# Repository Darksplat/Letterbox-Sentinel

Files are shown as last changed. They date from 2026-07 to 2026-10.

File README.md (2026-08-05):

# Letterbox Sentinel

Letterbox Sentinel is a battery-powered ESP8266/Wemos D1 Mini mail detector for Home Assistant using MQTT Discovery.

Current firmware: **v3.1.0**

## What it does

- Detects each separate delivery through the mail slot using an IR break-beam sensor.
- Supports multiple deliveries per day, even while `Mail Waiting` is already ON.
- Keeps a persistent `Mail Waiting` state until the mailbox is emptied.
- Keeps a persistent lifetime delivery counter.
- Records the most recent mail detection time.
- Supports NFC-driven collection through Home Assistant, including the collector name.
- Publishes BME280 temperature, humidity and sea-level-corrected pressure.
- Monitors a 2S 18650 battery pack through A0.
- Publishes Wi-Fi, network and device diagnostics to Home Assistant.
- Supports Arduino OTA updates.
- Uses timed deep sleep outside delivery hours to extend battery life.
- Uses DHCP by default so it can work on different home-network address ranges.

## Daily operating schedule

### Monday-Saturday

- **07:30**: IR mail monitoring begins.
- **17:00**: IR monitoring ends and scheduled deep-sleep operation begins.
- Every genuine delivery:
  - sets `Mail Waiting` to ON;
  - increments the persistent delivery counter;
  - updates `Last Mail Detected`;
  - publishes a mail event to MQTT;
  - turns the IR emitter off for 30 seconds;
  - automatically rearms the IR detector after the lockout.

The detector continues to accept later deliveries during the same day. Mail does not need to be collected before another delivery can be detected.

### Sunday

The IR system remains disabled and the ESP8266 uses scheduled deep sleep.

Deep sleep is performed in chunks of up to 60 minutes. The final sleep before 07:30 is shortened so the device wakes close to the monitoring start time.

## Mail Waiting and delivery counting

`Mail Waiting` and the delivery detector are deliberately independent:

- `Mail Waiting` answers: **Is there uncollected mail in the box?**
- The delivery counter answers: **How many separate deliveries have been detected?**

Example:

```text
10:00 Australia Post delivery
Mail Waiting: ON
Letter Counter: 1

14:00 Courier delivery
Mail Waiting: still ON
Letter Counter: 2

16:00 NFC collection
Mail Waiting: OFF
Letter Counter: still 2
```

Clearing `Mail Waiting` does not reset the lifetime counter.

## Hardware

- Wemos/LOLIN D1 Mini (ESP8266)
- BME280 environmental sensor
- IR break-beam receiver
- IR emitter
- BC547 transistor for IR emitter switching
- 2S 18650 battery pack
- TRACO Power TSR 1-2433 3.3 V switching regulator
- 330 kΩ / 100 kΩ battery voltage divider
- Optional 100 nF capacitor on A0
- D0/GPIO16 to RST connection for timed deep-sleep wake

### Custom PCB

A custom 2-layer KiCad carrier PCB has been developed for Letterbox Sentinel. The hardware design is documented under [`hardware/`](hardware/README.md).

Key PCB features:

- Approximately **64 mm × 50 mm**.
- Socketed Wemos D1 Mini for serviceability.
- Socketed **TRACO TSR 1-2433** 3.3 V regulator.
- Choice of **5.5 × 2.1 mm centre-positive barrel jack** or **AMASS XT60PW-F female** battery input.
- Raw 2S battery monitoring before regulation using the 330 kΩ / 100 kΩ divider.
- 1000 µF / 25 V reservoir capacitor on the 3.3 V rail.
- BC547-switched IR transmitter output.
- Female sockets for IR TX, IR RX and BME280.
- Bottom-layer GND copper plane.
- Through-hole construction for practical hand assembly and repair.

The routed board passed KiCad DRC with **0 errors and 0 unconnected pads** during the manufacturing review.

## Pinout

| Function | D1 Mini pin |
|---|---|
| BME280 SCL | D1 |
| BME280 SDA | D2 |
| IR receiver signal | D5 |
| IR emitter transistor control | D6 |
| Battery voltage | A0 |
| Deep-sleep wake | D0/GPIO16 → RST |

## IR emitter switching

D6 is a control signal only. Do not power the IR emitter directly from D6.

```text
D6 ---- 4.7k ---- BC547 base
BC547 emitter ---- GND
BC547 collector -- IR emitter negative
IR emitter positive -- 3.3 V rail
```

The IR receiver remains connected to D5.

## Battery monitoring

Current external divider:

```text
Battery + ---- 330k ----+---- A0
                        |
                      100k
                        |
Battery - ------------- GND
```

The current firmware uses:

```cpp
const float ADC_FULL_SCALE_V = 3.20F;
const float BATTERY_DIVIDER_RATIO = 5.35F;
const float BATTERY_CALIBRATION = 0.975F;
```

These values were calibrated against a multimeter on the installed Wemos D1 Mini and divider network. Other boards may require recalibration.

## BME280 pressure

Pressure is corrected to sea level using the configured site altitude:

```cpp
const float SITE_ALTITUDE_METERS = 230.0F;
```

The default is approximately 230 m above sea level for Maiden Gully, Victoria. Change this value for another installation location.

## Network configuration

Firmware v3.1.0 uses **DHCP by default**:

```cpp
const bool USE_STATIC_IP = false;
```

This means the device can join networks using address ranges such as:

- `192.168.0.x`
- `192.168.1.x`
- `10.x.x.x`
- `172.16.x.x`

For a stable address, the recommended approach is to leave DHCP enabled and create a DHCP reservation in the router.

Static addressing is optional. The static IP, gateway, subnet and DNS values are ignored unless:

```cpp
const bool USE_STATIC_IP = true;
```

## MQTT broker address

The public firmware defaults to:

```cpp
const char* MQTT_HOST = "homeassistant.local";
```

This may be replaced with:

- the MQTT broker hostname;
- the Home Assistant hostname if the broker runs there; or
- the broker's IP address.

The MQTT broker does not have to run on Home Assistant.

## NFC mail collection

The NFC tag is read by a phone running Home Assistant. It is not read directly by the Wemos.

Home Assistant should publish to:

```text
letterbox_sentinel/command/mail_collected
```

Example payload:

```json
{"collector":"Leigh"}
```

The firmware then:

- clears `Mail Waiting`;
- stores and publishes the collector name;
- stores and publishes the collection time;
- keeps the lifetime delivery counter unchanged.

The manual **Clear Mail Waiting** button performs the same state clear without requiring NFC.

## Home Assistant MQTT Discovery

The firmware automatically creates sensors, binary sensors and buttons in Home Assistant using MQTT Discovery.

### Stable identifier rule

From firmware **v2.2.0 onward**, MQTT Discovery identifiers are treated as a stable API:

- Discovery object IDs remain unchanged across firmware revisions.
- `unique_id` values remain unchanged across firmware revisions.
- Display names, icons, units, calibration and firmware logic may change without changing identifiers.
- If an entity must be removed or replaced, the obsolete retained MQTT Discovery topic must be cleared.

This prevents duplicate and orphaned Home Assistant entities during upgrades.

## Home Assistant controls

Current controls include:

- Clear Mail Waiting
- Reset Letter Counter
- Test Mail Detection
- Restart
- Enter Safe Mode
- Exit Safe Mode

The **Test Mail Detection** button creates a test event but does not start the 30-second physical IR lockout.

## Home Assistant entities

Important entities include:

- Mail Waiting
- Mail Slot Beam
- IR Emitter Active
- Letter Counter
- Last Mail Detected
- Last Collected By
- Last Collection Time
- Battery
- Battery Voltage
- Low Battery
- Temperature
- Humidity
- Sea Level Pressure
- Wi-Fi Signal
- Uptime
- IP Address
- Wi-Fi SSID
- MAC Address
- Gateway
- DNS Server
- Reset Reason
- Firmware
- Safe Mode
- Network Time Valid

## Required Arduino libraries

Install using **Arduino IDE → Library Manager**:

- PubSubClient
- ArduinoJson 7
- Adafruit BME280 Library
- Adafruit Unified Sensor

Also install ESP8266 board support and select the correct Wemos/LOLIN D1 Mini board.

## Firmware setup

Open:

```text
Letterbox_Sentinel_v3_1_0.ino
```

Edit only the clearly marked:

```cpp
// USER CONFIGURATION - EDIT THIS SECTION ONLY
```

At minimum, configure:

- Wi-Fi SSID and password;
- MQTT host, port, username and password;
- OTA password;
- site altitude;
- operating hours if different;
- DHCP or optional static IP settings.

The public repository intentionally contains placeholders instead of private Wi-Fi, MQTT and OTA credentials.

## Security

Never commit real Wi-Fi, MQTT or OTA passwords to a public repository.

Use placeholders such as:

```cpp
const char* WIFI_SSID = "CHANGE_WIFI_SSID";
const char* WIFI_PASSWORD = "CHANGE_WIFI_PASSWORD";
const char* MQTT_PASSWORD = "CHANGE_MQTT_PASSWORD";
const char* OTA_PASSWORD = "CHANGE_OTA_PASSWORD";
```

## Additional setup guide

See:

```text
Letterbox_Sentinel_v3_1_0_SETUP.md
```

for detailed first-time installation, Arduino IDE, DHCP/static IP, MQTT and testing instructions.

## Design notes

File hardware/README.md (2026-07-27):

# Letterbox Sentinel PCB Hardware

This directory contains the KiCad hardware design for the Letterbox Sentinel carrier PCB.

## Current PCB design

- 2-layer FR-4 PCB
- Approximate board size: 64 mm x 50 mm
- Wemos/LOLIN D1 Mini (ESP8266) on removable female headers
- Socketed TRACO Power TSR 1-2433 3.3 V switching regulator
- Dual 2S battery input options: 5.5 x 2.1 mm centre-positive barrel jack or AMASS XT60PW-F female PCB connector
- 1N5819 input protection
- 1000 uF / 25 V 3.3 V reservoir capacitor
- 330 kOhm / 100 kOhm raw-battery divider to A0
- BC547-switched IR transmitter
- Female sockets for IR TX, IR RX and BME280
- Bottom-layer GND copper plane

## Important power note

Use either the barrel jack or XT60 input. Do not connect two independent power sources at the same time.

The battery-voltage divider senses the raw 2S input before regulation.

## KiCad files

The authoritative current schematic and routed PCB are in `kicad/`.

The PCB has been manually routed and checked in KiCad with no DRC errors and no unconnected pads at the final review stage. Any future schematic-to-PCB update should be reviewed carefully so the established component placement and routing are not unintentionally disturbed.

## Manufacturing

`manufacturing/` contains available fabrication drill outputs from the current KiCad project. Gerber files should be regenerated from the authoritative PCB immediately before placing a manufacturing order.

Suggested standard PCB specification:

- 2 layers
- FR-4
- 1.6 mm thickness
- 1 oz copper
- Green solder mask
- White silkscreen
- Lead-free HASL

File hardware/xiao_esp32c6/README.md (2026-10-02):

# Letterbox Sentinel — XIAO ESP32-C6 carrier revision C6-1

This is a separate hardware revision for the **Seeed Studio XIAO ESP32-C6**, retaining the 64 × 50 mm carrier outline and 2S battery inputs. The original ESP8266 design remains in the parent hardware directory.

## Changes

- Two removable 1×7 sockets, 2.54 mm pitch, **17.78 mm row spacing**. USB faces the bottom edge marked USB THIS EDGE. With USB facing the bottom edge, D0 is the bottom pin of the right-hand physical row and 5V is the bottom pin of the left-hand physical row. Use female sockets tall enough to clear the components underneath the XIAO; verify clearance with the actual board before fabrication.
- Remove BME280 connector and its I2C nets. No temperature, humidity or pressure sensing.
- Remove ESP8266 D0-to-RST wake connection.
- Keep the IR transmitter, receiver, BC547 switching circuit and battery divider.
- Add C2, a 100 nF ceramic capacitor, across the ADC divider's lower resistor.
- Replace the **TSR 1-2433** with **TSR 1-2450 (5 V)**. Its output supplies the XIAO 5V pin. The XIAO 3V3 output supplies the IR circuit and C1. Do not fit the old 3.3 V regulator to this revision.
- Correct D1's physical footprint numbering: **pad 1 = cathode = VIN_PROTECTED; pad 2 = anode = BAT_RAW+**. The diode's band faces the protected regulator supply.
- Correct Q1 to BC547's C-B-E pin order: **pad 1 collector = IR_TX_SW_GND; pad 2 base = Q1_BASE; pad 3 emitter = GND**. Verify the actual transistor manufacturer's pinout when assembling.
- Reroute both copper layers; the original ground pour is replaced by routed ground connections. A provisional clear area is reserved near the module's antenna end. RF clearance and reception must be confirmed with the actual XIAO and letterbox enclosure; this is not a manufacturer-approved RF layout.

## Firmware pin mapping

| Function | XIAO pin | ESP32-C6 GPIO |
|---|---|---|
| Battery ADC | D0 / A0 | GPIO0 |
| IR receiver | D1 | GPIO1 |
| IR emitter control | D2 | GPIO2 |
| Regulated supply input | 5V | — |
| IR supply output | 3V3 | — |
| Ground | GND | — |

The 330 kΩ / 100 kΩ divider ratio is **4.3**. At 8.4 V battery voltage, ADC voltage is approximately **1.953 V**. The old Wemos calibration factor 5.35 does not apply. Use appropriate ESP32-C6 ADC attenuation, calibrated millivolt readings and multimeter calibration. The 100 nF filter helps the high-impedance divider settle.

## Battery and power limitations

The TSR 1-2450 requires **at least 6.5 V at its input**. The protection diode reduces voltage before the regulator, so operation near the bottom of a 2S pack's discharge range is not guaranteed. A **7.0 V raw-pack low-battery threshold is an initial warning target**, not a hardware cutoff or a substitute for a protected/balanced 2S pack. Confirm voltage under load. This choice sacrifices usable capacity compared with the original 3.3 V regulator; a future low-quiescent-current power revision could improve endurance.

Use only one battery input at a time. Disconnect the carrier's battery supply before connecting the XIAO USB port, because its 5V pin shares USB VBUS. Leave XIAO BAT pads unused: they are for a single lithium cell, not this 2S pack. Confirm the IR modules' supply current is within the XIAO 3V3 regulator's capacity.

## Thread and Home Assistant

This hardware supports the ESP32-C6 radio. **The existing ESP8266 Wi-Fi/MQTT firmware has not been ported and cannot run on this board.** A separate ESP32-C6 firmware implementation is needed for Thread/OpenThread or Matter over Thread, including delivery counting, mail state, collection commands and the operating schedule. Thread alone does not provide Matter entities. A Thread border router is required. The ESP8266 deep-sleep behavior must be revisited because a sleeping device cannot remain available for collection commands.

## Opening and review

Open `Letterbox_Sentinel_C6.kicad_pro` in KiCad 10. The schematic, PCB, symbol library, footprint library and both library tables are included. Keep the entire directory together.

The revision has been checked in KiCad CLI 10.0.6. See `validation/` for the actual reports. Electrical DRC and ERC errors: zero. Unconnected PCB pads: zero. Schematic-to-PCB parity issues: zero. The isolated CLI environment still reports local footprint-library availability warnings; rerun full checks after opening the project in desktop KiCad.

This is a **review revision**, not a released manufacturing package: verify module orientation, socket height, USB access, antenna clearance, IR current draw and regulator behavior with the actual components. No Gerbers are supplied, and old manufacturing files are for the ESP8266 revision only.

## Primary references

- https://wiki.seeedstudio.com/xiao_esp32c6_getting_started/
- https://wiki.seeedstudio.com/xiao_pin_multiplexing_esp32c6/
- https://www.tracopower.com/sites/default/files/products/datasheets/tsr1_datasheet.pdf
- https://www.onsemi.com/download/data-sheet/pdf/bc546-d.pdf

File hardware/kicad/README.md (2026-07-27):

# KiCad source

The authoritative Letterbox Sentinel KiCad project consists of:

- `Letterbox_Sentinel.kicad_pro`
- `Letterbox_Sentinel.kicad_sch`
- `Letterbox_Sentinel.kicad_pcb`

The final reviewed source files were produced in KiCad 10 on 27 July 2026.

## Current design status

- Board: approximately 64 mm x 50 mm
- 2-layer through-hole design
- Manual routing completed
- Bottom GND plane
- KiCad DRC: 0 errors, 0 unconnected pads at final review
- Mechanical fit reviewed before fabrication

Before ordering a future revision, open the project in KiCad, refill zones (`B`) and rerun DRC.

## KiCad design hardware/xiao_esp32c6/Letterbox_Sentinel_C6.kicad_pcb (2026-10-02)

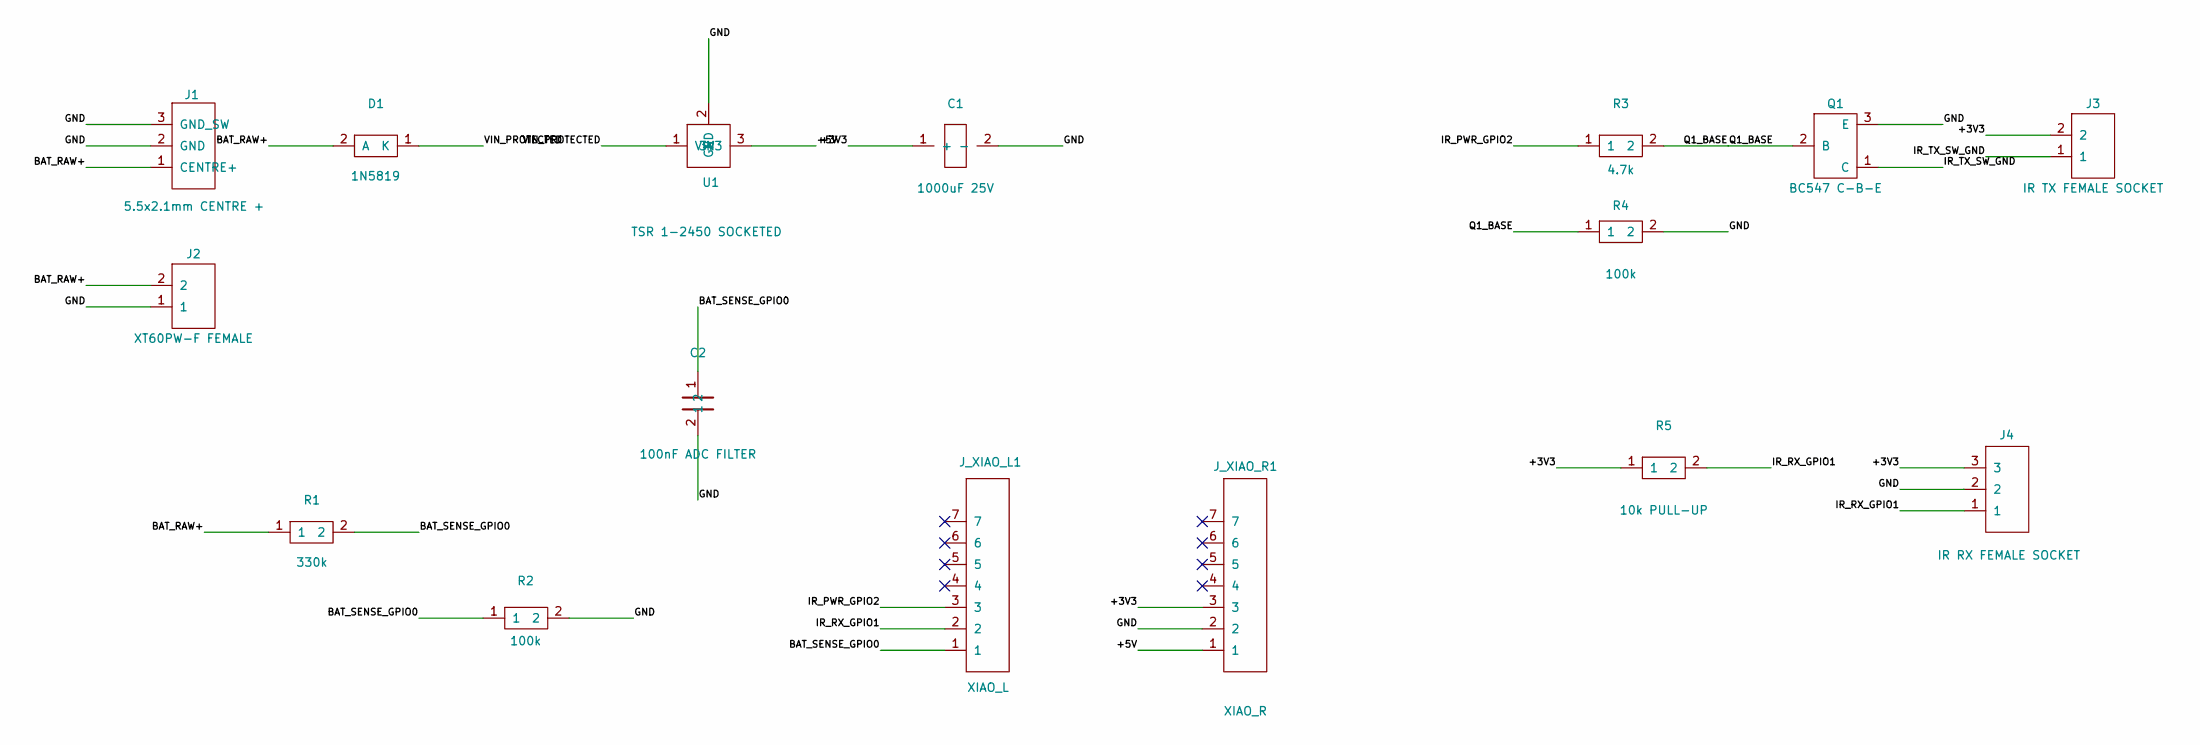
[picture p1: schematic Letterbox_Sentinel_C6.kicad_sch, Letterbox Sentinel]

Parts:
C1: 1000uF 25V; CP_Radial_D12.5mm_P5.00mm_C1
C2: 100nF ADC FILTER; C_Disc_D5.0mm_W2.5mm_P5.00mm_C2
D1: 1N5819; D_DO-41_SOD81_P10.16mm_Horizontal_D1
J1: 5.5x2.1mm CENTRE +; BarrelJack_GCT_DCJ200-10-A_Horizontal_J1
J2: XT60PW-F FEMALE; AMASS_XT60PW-F_1x02_P7.20mm_Horizontal_J2
J3: IR TX FEMALE SOCKET; PinSocket_1x02_P2.54mm_Vertical_J3
J4: IR RX FEMALE SOCKET; PinSocket_1x03_P2.54mm_Vertical_J4
J_XIAO_L1: XIAO_L; PinSocket_1x07_P2.54mm_Vertical_J_XIAO_L1
J_XIAO_R1: XIAO_R; PinSocket_1x07_P2.54mm_Vertical_J_XIAO_R1
Q1: BC547 C-B-E; TO-92_Inline_Wide_Q1
R1: 330k; R_Axial_DIN0207_L6.3mm_D2.5mm_P10.16mm_Horizontal_R1
R2: 100k; R_Axial_DIN0207_L6.3mm_D2.5mm_P10.16mm_Horizontal_R2
R3: 4.7k; R_Axial_DIN0207_L6.3mm_D2.5mm_P10.16mm_Horizontal_R3
R4: 100k; R_Axial_DIN0207_L6.3mm_D2.5mm_P10.16mm_Horizontal_R4
R5: 10k PULL-UP; R_Axial_DIN0207_L6.3mm_D2.5mm_P10.16mm_Horizontal_R5
U1: TSR 1-2450 SOCKETED; PinSocket_1x03_P2.54mm_Vertical_U1

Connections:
/+3V3: C1.1 (+), J3.2, J4.3, J_XIAO_R1.3, R5.1
/+5V: J_XIAO_R1.1, U1.3 (3V3)
/BAT_RAW+: D1.2 (A), J1.1 (CENTRE+), J2.2, R1.1
/BAT_SENSE_GPIO0: C2.1, J_XIAO_L1.1, R1.2, R2.1
/GND: C1.2 (-), C2.2, J1.2 (GND), J1.3 (GND_SW), J2.1, J4.2, J_XIAO_R1.2, Q1.3 (E), R2.2, R4.2, U1.2 (GND)
/IR_PWR_GPIO2: J_XIAO_L1.3, R3.1
/IR_RX_GPIO1: J4.1, J_XIAO_L1.2, R5.2
/IR_TX_SW_GND: J3.1, Q1.1 (C)
/Q1_BASE: Q1.2 (B), R3.2, R4.1
/VIN_PROTECTED: D1.1 (K), U1.1 (VIN)

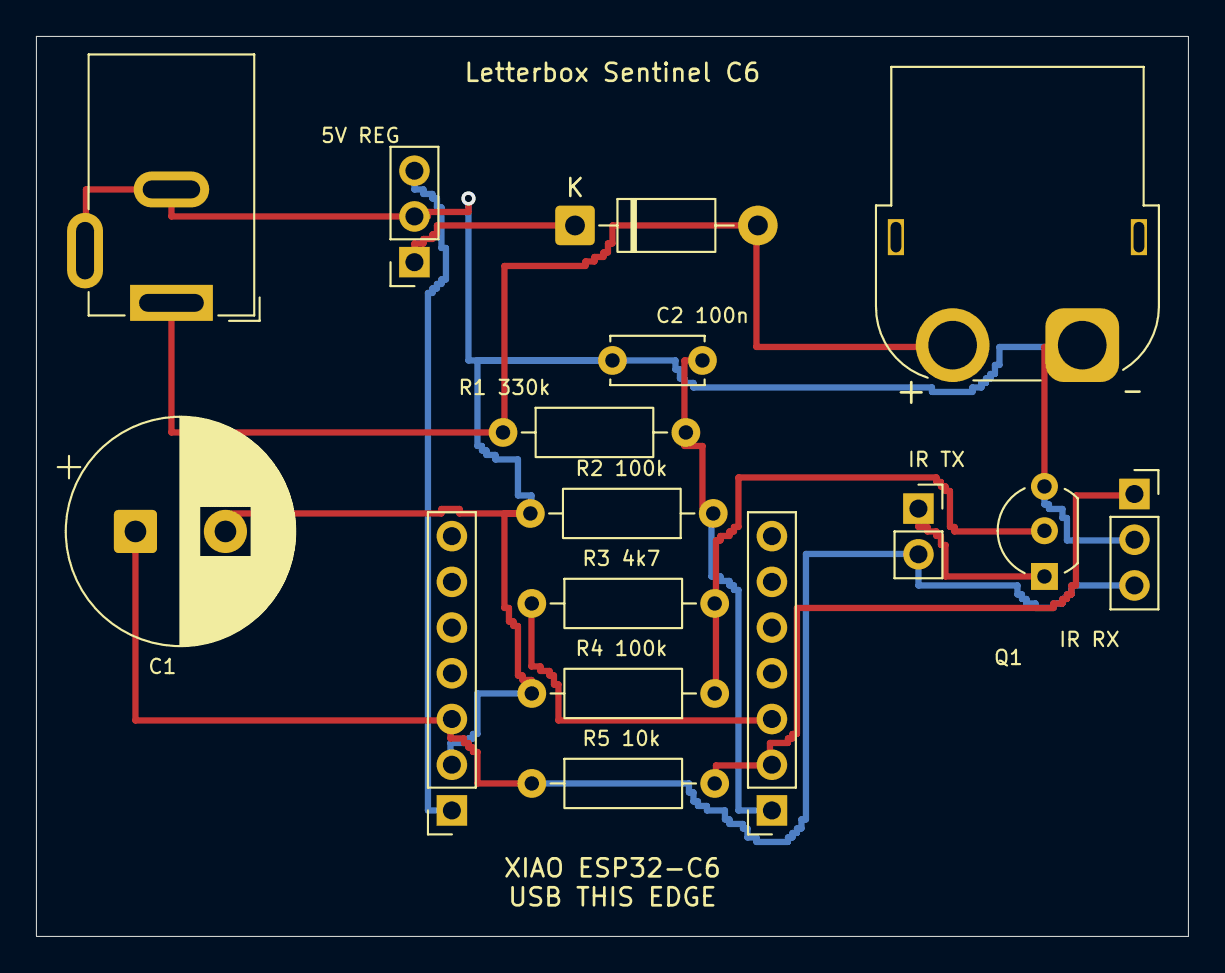
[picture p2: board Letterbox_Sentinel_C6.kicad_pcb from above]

Board: 2 copper layers, 64.0 x 50.0 mm, 16 parts (0 on the bottom side), 10 nets.

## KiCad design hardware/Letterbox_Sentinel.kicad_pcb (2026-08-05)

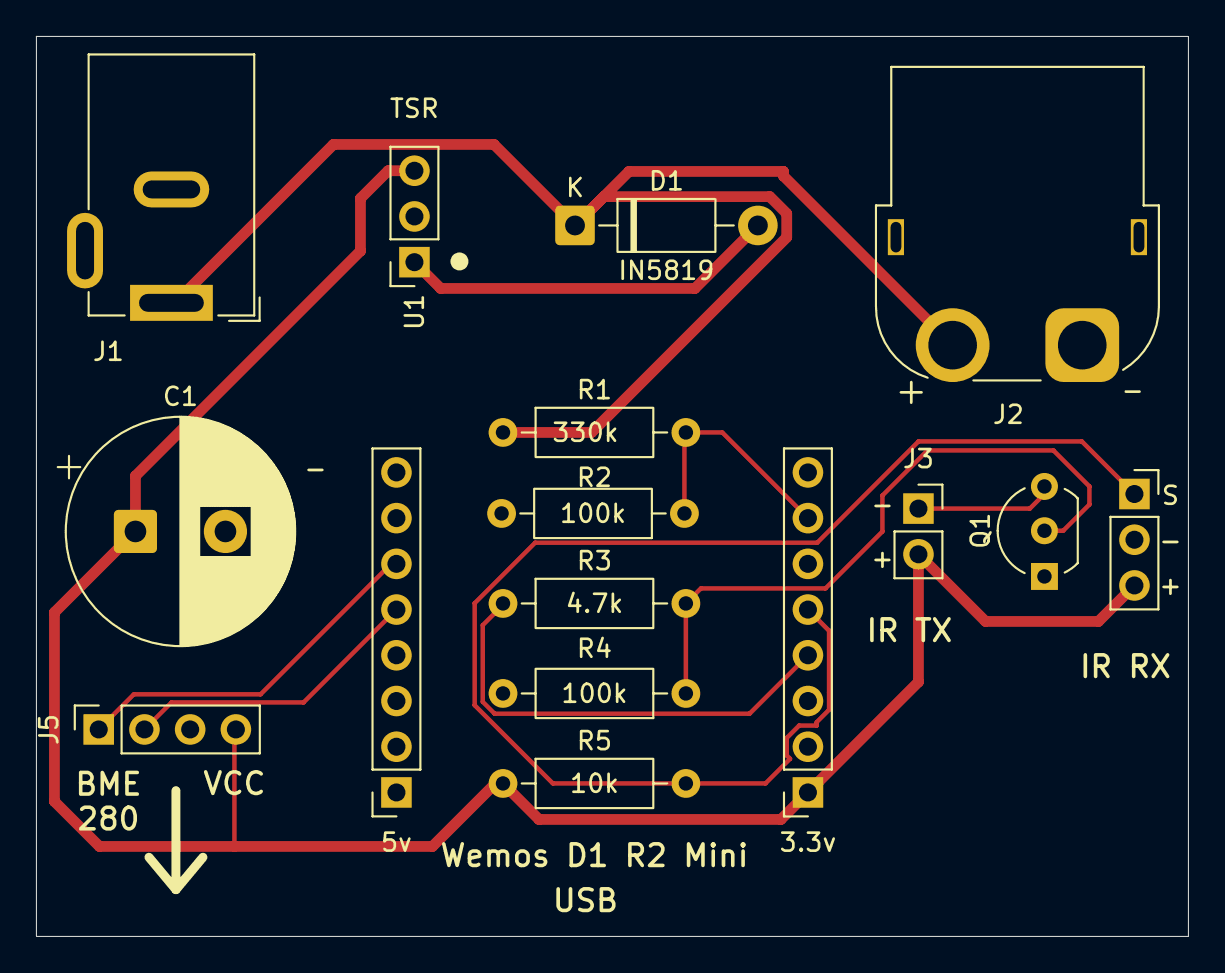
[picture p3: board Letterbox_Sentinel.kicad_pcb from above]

Board: 2 copper layers, 64.0 x 50.0 mm, 16 parts (0 on the bottom side), 11 nets.

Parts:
3.3v: WEMOS LEFT; PinSocket_1x08_P2.54mm_Vertical
5v: WEMOS RIGHT; PinSocket_1x08_P2.54mm_Vertical
C1: 1000uF 25V; CP_Radial_D12.5mm_P5.00mm
D1: 1N5819; D_DO-41_SOD81_P10.16mm_Horizontal
J1: 5.5x2.1mm CENTRE +; BarrelJack_GCT_DCJ200-10-A_Horizontal
J2: XT60PW-F FEMALE; AMASS_XT60PW-F_1x02_P7.20mm_Horizontal
J3: IR TX FEMALE SOCKET; PinSocket_1x02_P2.54mm_Vertical
J5: BME280 FEMALE SOCKET; PinSocket_1x04_P2.54mm_Vertical
Q1: BC547 C-B-E; TO-92_Inline_Wide
R1: 330k; R_Axial_DIN0207_L6.3mm_D2.5mm_P10.16mm_Horizontal
R2, R4: 100k; R_Axial_DIN0207_L6.3mm_D2.5mm_P10.16mm_Horizontal
R3: 4.7k; R_Axial_DIN0207_L6.3mm_D2.5mm_P10.16mm_Horizontal
R5: 10k PULL-UP; R_Axial_DIN0207_L6.3mm_D2.5mm_P10.16mm_Horizontal
S: IR RX FEMALE SOCKET; PinSocket_1x03_P2.54mm_Vertical
U1: TSR 1-2433 SOCKETED; PinSocket_1x03_P2.54mm_Vertical

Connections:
/+3V3: 3.3v.1, C1.1 (+), J3.2, J5.4, R5.1, S.3, U1.3 (3V3)
/BAT_RAW+: D1.1 (A), J1.1 (CENTRE+), J2.2, R1.1
/BAT_SENSE_A0: 3.3v.7, R1.2, R2.1
/GND: 5v.2, C1.2 (-), J1.2 (GND), J1.3 (GND_SW), J2.1, J5.3, Q1.1 (C), R2.2, R4.2, S.2, U1.2 (GND)
/I2C_SCL_D1: 5v.6, J5.1
/I2C_SDA_D2: 5v.5, J5.2
/IR_PWR_CTL_D6: 3.3v.4, R3.1
/IR_RX_SIG_D5: 3.3v.5, R5.2, S.1
/IR_TX_SW_GND: J3.1, Q1.3 (E)
/Q1_BASE: Q1.2 (B), R3.2, R4.1
/VIN_PROTECTED: D1.2 (K), U1.1 (VIN)

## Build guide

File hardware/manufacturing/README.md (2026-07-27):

# Manufacturing outputs

Current drill outputs from KiCad 10 are stored here for reference.

For an actual PCBWay order, regenerate the complete Gerber and Excellon set from the authoritative KiCad PCB immediately before ordering. Do not manufacture from drill files alone.

Recommended PCB specification:

- 2 layers
- FR-4
- 1.6 mm thickness
- 1 oz copper
- Green solder mask
- White silkscreen
- Lead-free HASL

Final design review status on 27 July 2026:

- KiCad DRC: 0 errors
- Unconnected pads: 0
- Through-hole rear solder pads visually confirmed in KiCad 3D Viewer
- Physical component clearances reviewed

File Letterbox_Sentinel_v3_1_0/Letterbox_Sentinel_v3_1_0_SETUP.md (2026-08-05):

# Letterbox Sentinel v3.1.0 — Setup Guide

This release makes the firmware portable across different home networks. It uses **DHCP by default**, so it does not assume that the network is `192.168.0.x`.

## 1. Required hardware

- LOLIN/Wemos D1 Mini (ESP8266)
- BME280 environmental sensor
- IR break-beam receiver on D5
- IR emitter switched from D6 through the transistor circuit
- 2S 18650 battery system and regulated 3.3 V supply
- 330 kΩ / 100 kΩ battery voltage divider to A0
- D0/GPIO16 connected to RST for timed deep-sleep wake

## 2. Required Arduino libraries

Install through **Arduino IDE → Tools → Manage Libraries**:

- PubSubClient
- ArduinoJson 7
- Adafruit BME280 Library
- Adafruit Unified Sensor

Also install the ESP8266 board package and select the correct Wemos/LOLIN D1 Mini board.

## 3. Edit only the USER CONFIGURATION section

Open `Letterbox_Sentinel_v3_1_0.ino` and locate:

```cpp
// USER CONFIGURATION - EDIT THIS SECTION ONLY
```

Enter the following values.

### Wi-Fi

```cpp
const char* WIFI_SSID = "YOUR_WIFI_NAME";
const char* WIFI_PASSWORD = "YOUR_WIFI_PASSWORD";
```

The ESP8266 requires a 2.4 GHz Wi-Fi network.

### MQTT broker

```cpp
const char* MQTT_HOST = "homeassistant.local";
const uint16_t MQTT_PORT = 1883;
const char* MQTT_USERNAME = "YOUR_MQTT_USERNAME";
const char* MQTT_PASSWORD = "YOUR_MQTT_PASSWORD";
```

`MQTT_HOST` can be a hostname or an IP address. Examples:

```cpp
const char* MQTT_HOST = "homeassistant.local";
```

or:

```cpp
const char* MQTT_HOST = "192.168.1.50";
```

Home Assistant and the MQTT broker are not necessarily the same service. When Mosquitto is installed as a Home Assistant add-on, the Home Assistant hostname or IP normally points to the correct machine.

### OTA password

```cpp
const char* OTA_PASSWORD = "CHOOSE_A_STRONG_PASSWORD";
```

The first firmware upload normally uses USB. Later updates can be uploaded wirelessly through Arduino OTA while the device is awake and connected.

## 4. DHCP or static IP

The default is:

```cpp
const bool USE_STATIC_IP = false;
```

Leave this as `false` for normal installations. The router will assign an address automatically, regardless of whether the network uses `192.168.0.x`, `192.168.1.x`, `10.x.x.x`, or another private subnet.

### Recommended fixed-address method

Leave DHCP enabled and create a **DHCP reservation** in the router for the Letterbox Sentinel MAC address. This gives the device a predictable address without hard-coding network details into the firmware.

### Optional firmware static IP

Only use this when all network values are known:

```cpp
const bool USE_STATIC_IP = true;

IPAddress DEVICE_IP(192, 168, 1, 220);
IPAddress GATEWAY_IP(192, 168, 1, 1);
IPAddress SUBNET_MASK(255, 255, 255, 0);
IPAddress DNS_SERVER(192, 168, 1, 1);
```

The address must be valid and unused on the installer's network.

## 5. Timezone and schedule

The supplied timezone rule is for Victoria, Australia:

```cpp
const char* TIMEZONE_RULE = "AEST-10AEDT,M10.1.0,M4.1.0/3";
```

The default monitoring period is Monday–Saturday from 7:30 am to 5:00 pm:

```cpp
const uint8_t IR_START_HOUR = 7;
const uint8_t IR_START_MINUTE = 30;
const uint8_t IR_END_HOUR = 17;
const uint8_t IR_END_MINUTE = 0;
```

Sunday remains disabled.

## 6. Altitude and pressure

Set the installation altitude in metres above sea level:

```cpp
const float SITE_ALTITUDE_METERS = 230.0F;
```

This is used to publish weather-style sea-level pressure rather than raw station pressure.

## 7. Battery calibration

The supplied values match the documented 330 kΩ / 100 kΩ divider and the tested D1 Mini:

```cpp
const float ADC_FULL_SCALE_V = 3.20F;
const float BATTERY_DIVIDER_RATIO = 5.35F;
const float BATTERY_CALIBRATION = 0.975F;
```

After installation, compare the Home Assistant battery voltage with a multimeter. Fine-tune only `BATTERY_CALIBRATION` if necessary.

Example: if Home Assistant reads 8.00 V and the multimeter reads 7.80 V:

```text
7.80 / 8.00 = 0.975
```

## 8. First upload and serial check

Upload by USB, then open Serial Monitor at **115200 baud**. Confirm:

- Wi-Fi connects
- the assigned IP address is shown
- MQTT connects
- Home Assistant discovery publishes
- BME280 is detected
- Network Time Valid becomes ON
- IR Emitter Active follows the schedule

When DHCP is used, the serial log will show:

```text
Network mode: DHCP
Wi-Fi connected: <assigned address>
Gateway: <router address>
DNS server: <DNS address>
Address source: DHCP
```

## 9. Home Assistant

The device should appear under:

**Settings → Devices & services → MQTT → Devices**

The MQTT Discovery object IDs and `unique_id` values remain stable from v2.2.0 onward. Future firmware changes must not change them casually, because doing so creates duplicate/orphaned entities in Home Assistant.

## 10. Security before publishing

Never commit real credentials to a public GitHub repository. Replace them with placeholders before publishing:

```cpp
const char* WIFI_SSID = "CHANGE_WIFI_SSID";
const char* WIFI_PASSWORD = "CHANGE_WIFI_PASSWORD";
const char* MQTT_USERNAME = "CHANGE_MQTT_USERNAME";
const char* MQTT_PASSWORD = "CHANGE_MQTT_PASSWORD";
const char* OTA_PASSWORD = "CHANGE_OTA_PASSWORD";
```

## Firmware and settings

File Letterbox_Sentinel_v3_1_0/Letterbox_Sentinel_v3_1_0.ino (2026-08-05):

/*
  Letterbox Sentinel v3.1.0
  Board: LOLIN/Wemos D1 mini (ESP8266)

  FEATURES
  --------
  - BME280 on D1/D2
  - Sea-level corrected pressure for Maiden Gully (~230 m ASL)
  - IR receiver on D5
  - Scheduled IR emitter control on D6 via transistor
  - IR active Monday-Saturday, 07:30-17:00
  - IR disabled overnight and all Sunday
  - Persistent Mail Waiting state
  - Persistent lifetime letter counter
  - NFC/Home Assistant collection command with collector name
  - Battery voltage and estimated percentage on A0
  - Battery divider calibrated for current hardware
  - Arduino OTA
  - Home Assistant MQTT Discovery
  - Persistent state in EEPROM
  - Proven ESP8266 timed deep sleep outside IR operating hours
  - IR transmitter forced OFF before every sleep
  - D0/GPIO16 -> RST timed wake support
  - Maximum 60-minute sleep chunks so time/MQTT are refreshed periodically
  - Multiple deliveries per day, even while Mail Waiting remains ON
  - 30-second IR lockout after each genuine delivery, then automatic rearm
  - Mail Waiting remains persistent until NFC/manual collection

  DEEP SLEEP WIRING
  -----------------
  D0 / GPIO16 -> RST is REQUIRED for automatic wake-up.

  REQUIRED LIBRARIES
  ------------------
  PubSubClient
  ArduinoJson 7
  Adafruit BME280 Library
  Adafruit Unified Sensor
*/

#include <ESP8266WiFi.h>
#include <PubSubClient.h>
#include <ArduinoOTA.h>
#include <Wire.h>
#include <Adafruit_Sensor.h>
#include <Adafruit_BME280.h>
#include <ArduinoJson.h>
#include <EEPROM.h>
#include <time.h>

// ============================================================
// USER CONFIGURATION - EDIT THIS SECTION ONLY
// ============================================================
//
// FIRST-TIME SETUP
// ----------------
// 1. Enter your Wi-Fi name and password.
// 2. Enter the hostname or IP address of your MQTT broker.
// 3. Enter your MQTT username and password.
// 4. Choose whether to use DHCP or a fixed/static IP address.
// 5. Set your timezone, site altitude and mail-monitoring hours.
//
// NETWORK ADDRESSING
// ------------------
// DHCP is enabled by default because it works on almost every home network,
// regardless of whether the LAN uses 192.168.0.x, 192.168.1.x, 10.x.x.x,
// 172.16.x.x, or another private address range.
//
// For a dependable fixed address, the recommended approach is:
//   - Leave USE_STATIC_IP set to false here; and
//   - Create a DHCP reservation in your router for this device's MAC address.
//
// Only set USE_STATIC_IP to true when you understand your router's subnet,
// gateway, DNS and available address range.

// Wi-Fi credentials.
const char* WIFI_SSID = "CHANGE_WIFI_SSID";
const char* WIFI_PASSWORD = "CHANGE_WIFI_PASSWORD";

// MQTT broker settings.
// This may be either:
//   - A hostname, such as "homeassistant.local" or "mqtt.local"; or
//   - A numeric IP address, such as "192.168.1.50".
//
// IMPORTANT: Home Assistant is not always the MQTT broker. If you use the
// Mosquitto add-on, the broker normally runs on the Home Assistant machine,
// so the Home Assistant hostname/IP will usually work.
const char* MQTT_HOST = "homeassistant.local";
const uint16_t MQTT_PORT = 1883;
const char* MQTT_USERNAME = "CHANGE_MQTT_USERNAME";
const char* MQTT_PASSWORD = "CHANGE_MQTT_PASSWORD";

// OTA settings used for wireless Arduino uploads after the first USB flash.
const char* OTA_HOSTNAME = "letterbox-sentinel";
const char* OTA_PASSWORD = "CHANGE_OTA_PASSWORD";

// DHCP is the safe and portable default.
const bool USE_STATIC_IP = false;

// These values are ignored while USE_STATIC_IP is false.
// Edit all four values before enabling a static IP.
IPAddress DEVICE_IP(192, 168, 1, 220);
IPAddress GATEWAY_IP(192, 168, 1, 1);
IPAddress SUBNET_MASK(255, 255, 255, 0);
IPAddress DNS_SERVER(192, 168, 1, 1);

// Melbourne/Victoria timezone, including automatic daylight saving.
// Installations elsewhere must replace this POSIX timezone rule.
const char* TIMEZONE_RULE = "AEST-10AEDT,M10.1.0,M4.1.0/3";
const char* NTP_SERVER_1 = "pool.ntp.org";
const char* NTP_SERVER_2 = "time.google.com";

// Site elevation used to convert raw station pressure to sea-level pressure.
// Change this to the approximate metres above sea level at your installation.
const float SITE_ALTITUDE_METERS = 230.0F;

// Battery calibration for the documented 330k/100k divider and this D1 Mini.
// Compare the Home Assistant voltage with a multimeter and adjust
// BATTERY_CALIBRATION if required.
const float ADC_FULL_SCALE_V = 3.20F;
const float BATTERY_DIVIDER_RATIO = 5.35F;
const float BATTERY_CALIBRATION = 0.975F;

// Daily IR monitoring window.
// Current default: Monday-Saturday, 07:30 until 17:00; Sunday disabled.
const uint8_t IR_START_HOUR = 7;
const uint8_t IR_START_MINUTE = 30;
const uint8_t IR_END_HOUR = 17;
const uint8_t IR_END_MINUTE = 0;

// Time the IR emitter remains off after a genuine delivery.
// This prevents one item of mail from being counted more than once, while
// allowing another later delivery to be detected even if mail is still waiting.
const unsigned long IR_POST_DELIVERY_LOCKOUT_MS = 30000;

// ============================================================
// HARDWARE
// ============================================================

const uint8_t IR_RECEIVER_PIN = D5;
const uint8_t IR_EMITTER_CONTROL_PIN = D6;

const uint8_t IR_EMITTER_ON_LEVEL = HIGH;
const uint8_t IR_EMITTER_OFF_LEVEL = LOW;

// IR receiver assumes LOW means beam interrupted.
const uint8_t IR_BEAM_BROKEN_LEVEL = LOW;

const unsigned long IR_DEBOUNCE_MS = 60;
const unsigned long IR_REARM_CLEAR_MS = 500;
const unsigned long IR_STARTUP_SETTLE_MS = 1000;
const unsigned long IR_MIN_EVENT_GAP_MS = 2000;
// Deep sleep is used only when the IR monitoring window is inactive.
// During Monday-Saturday 07:30-17:00 the ESP remains awake.
// Before the first real letter it continuously monitors the IR beam.
// Each genuine delivery starts a short IR lockout to prevent duplicate counts.
// Mail Waiting remains ON until NFC/manual collection, but the detector rearms
// automatically after the lockout so later deliveries are still counted.
//
// IMPORTANT: D0 / GPIO16 MUST be connected to RST for timed wake-up.
const uint64_t DEEP_SLEEP_MAX_US = 60ULL * 60ULL * 1000000ULL; // 60 minutes
const unsigned long DEEP_SLEEP_BOOT_GRACE_MS = 10000UL;        // allow MQTT/OTA/NTP after wake

// ============================================================
// DEVICE INFORMATION
// ============================================================

const char* DEVICE_ID = "letterbox_sentinel";
const char* DEVICE_NAME = "Letterbox Sentinel";
const char* FIRMWARE_VERSION = "3.1.0";
const char* DEVICE_MANUFACTURER = "DIY";
const char* DEVICE_MODEL = "Wemos D1 Mini Letterbox Sentinel";

// ============================================================
// MQTT TOPICS
// ============================================================

const char* TOPIC_AVAILABILITY = "letterbox_sentinel/status";

const char* TOPIC_TEMPERATURE = "letterbox_sentinel/bme280/temperature";
const char* TOPIC_HUMIDITY = "letterbox_sentinel/bme280/humidity";
const char* TOPIC_PRESSURE = "letterbox_sentinel/bme280/pressure";

const char* TOPIC_IR_BEAM = "letterbox_sentinel/mail_slot/beam";
const char* TOPIC_IR_EMITTER = "letterbox_sentinel/mail_slot/emitter_active";

const char* TOPIC_MAIL_WAITING = "letterbox_sentinel/mail/waiting";
const char* TOPIC_LETTER_COUNT = "letterbox_sentinel/mail/letter_count";
const char* TOPIC_LAST_MAIL = "letterbox_sentinel/mail/last_detected";
const char* TOPIC_LAST_COLLECTOR = "letterbox_sentinel/mail/last_collector";
const char* TOPIC_LAST_COLLECTION = "letterbox_sentinel/mail/last_collection";

const char* TOPIC_MAIL_EVENT = "letterbox_sentinel/event/mail_detected";
const char* TOPIC_COLLECTION_EVENT = "letterbox_sentinel/event/mail_collected";

const char* TOPIC_BATTERY_VOLTAGE = "letterbox_sentinel/battery/voltage";
const char* TOPIC_BATTERY_PERCENT = "letterbox_sentinel/battery/percent";
const char* TOPIC_LOW_BATTERY = "letterbox_sentinel/battery/low";

const char* TOPIC_WIFI_RSSI = "letterbox_sentinel/diagnostic/wifi_rssi";
const char* TOPIC_UPTIME = "letterbox_sentinel/diagnostic/uptime";
const char* TOPIC_IP = "letterbox_sentinel/diagnostic/ip";
const char* TOPIC_SSID = "letterbox_sentinel/diagnostic/ssid";
const char* TOPIC_MAC = "letterbox_sentinel/diagnostic/mac";
const char* TOPIC_GATEWAY = "letterbox_sentinel/diagnostic/gateway";
const char* TOPIC_DNS = "letterbox_sentinel/diagnostic/dns";
const char* TOPIC_RESET_REASON = "letterbox_sentinel/diagnostic/reset_reason";
const char* TOPIC_FREE_HEAP = "letterbox_sentinel/diagnostic/free_heap";
const char* TOPIC_FIRMWARE = "letterbox_sentinel/diagnostic/firmware";
const char* TOPIC_SAFE_MODE = "letterbox_sentinel/diagnostic/safe_mode";
const char* TOPIC_TIME_VALID = "letterbox_sentinel/diagnostic/time_valid";

const char* CMD_CLEAR_MAIL = "letterbox_sentinel/command/clear_mail";
const char* CMD_RESET_COUNTER = "letterbox_sentinel/command/reset_counter";
const char* CMD_TEST_MAIL = "letterbox_sentinel/command/test_mail";
const char* CMD_RESTART = "letterbox_sentinel/command/restart";
const char* CMD_SAFE_MODE = "letterbox_sentinel/command/safe_mode";
const char* CMD_EXIT_SAFE_MODE = "letterbox_sentinel/command/exit_safe_mode";
const char* CMD_MAIL_COLLECTED = "letterbox_sentinel/command/mail_collected";

const char* HOME_ASSISTANT_STATUS_TOPIC = "homeassistant/status";

// ============================================================
// TIMING
// ============================================================

const unsigned long SENSOR_PUBLISH_INTERVAL_MS = 60000;
const unsigned long NETWORK_PUBLISH_INTERVAL_MS = 300000;
const unsigned long SCHEDULE_CHECK_INTERVAL_MS = 1000;
const unsigned long WIFI_RETRY_INTERVAL_MS = 30000;
const unsigned long MQTT_RETRY_INTERVAL_MS = 5000;

// ============================================================
// PERSISTENT STORAGE
// ============================================================

const uint32_t PERSIST_MAGIC = 0x4C425332;
const uint16_t PERSIST_VERSION = 1;
const size_t EEPROM_SIZE = 512;

struct PersistentData {
  uint32_t magic;
  uint16_t version;
  uint16_t reserved;
  uint32_t letterCount;
  uint32_t bootCount;
  uint32_t lastMailEpoch;
  uint32_t lastCollectionEpoch;
  bool mailWaiting;
  bool safeMode;
  char lastCollector[40];
  uint32_t checksum;
};

PersistentData persistent;

// ============================================================
// OBJECTS
// ============================================================

WiFiClient wifiClient;
PubSubClient mqttClient(wifiClient);
Adafruit_BME280 bme280;

// ============================================================
// RUNTIME STATE
// ============================================================

bool bmeAvailable = false;
bool otaStarted = false;
bool timeConfigured = false;

bool emitterActive = false;
unsigned long emitterEnabledAtMs = 0;

bool rawBeamBroken = false;
bool stableBeamBroken = false;
bool mailDetectionArmed = false;

unsigned long rawBeamChangedAtMs = 0;
unsigned long beamClearSinceMs = 0;
unsigned long lastMailEventMs = 0;

unsigned long lastSensorPublishMs = 0;
unsigned long lastNetworkPublishMs = 0;
unsigned long lastScheduleCheckMs = 0;
unsigned long lastWiFiAttemptMs = 0;
unsigned long lastMQTTAttemptMs = 0;
bool sleepCheckedThisBoot = false;
unsigned long irLockoutUntilMs = 0;

// ============================================================
// PERSISTENCE
// ============================================================

uint32_t calculateChecksum(const PersistentData& data) {
  const uint8_t* bytes =
    reinterpret_cast<const uint8_t*>(&data);

  const size_t length =
    sizeof(PersistentData) - sizeof(data.checksum);

  uint32_t hash = 2166136261UL;

  for (size_t i = 0; i < length; i++) {
    hash ^= bytes[i];
    hash *= 16777619UL;
  }

  return hash;
}

void savePersistentData() {
  persistent.magic = PERSIST_MAGIC;
  persistent.version = PERSIST_VERSION;
  persistent.checksum = calculateChecksum(persistent);

  EEPROM.put(0, persistent);
  EEPROM.commit();
}

void loadPersistentData() {
  EEPROM.begin(EEPROM_SIZE);
  EEPROM.get(0, persistent);

  const bool valid =
    persistent.magic == PERSIST_MAGIC &&
    persistent.version == PERSIST_VERSION &&
    persistent.checksum == calculateChecksum(persistent);

  if (!valid) {
    memset(&persistent, 0, sizeof(persistent));

    persistent.magic = PERSIST_MAGIC;
    persistent.version = PERSIST_VERSION;
    persistent.mailWaiting = false;
    persistent.safeMode = false;

    strlcpy(
      persistent.lastCollector,
      "Never collected",
      sizeof(persistent.lastCollector)
    );
  }

  persistent.bootCount++;
  savePersistentData();
}

// ============================================================
// TIME
// ============================================================

bool timeIsValid() {
  return time(nullptr) > 1700000000;
}

String epochToIso8601(uint32_t epoch) {
  if (epoch == 0) {
    return "unknown";
  }

  time_t raw = static_cast<time_t>(epoch);

  struct tm utcTime;
  gmtime_r(&raw, &utcTime);

  char buffer[28];

  strftime(
    buffer,
    sizeof(buffer),
    "%Y-%m-%dT%H:%M:%SZ",
    &utcTime
  );

  return String(buffer);
}

// ============================================================
// MQTT HELPERS
// ============================================================

bool publishRetained(const char* topic, const String& value) {
  if (!mqttClient.connected()) return false;

  return mqttClient.publish(
    topic,
    value.c_str(),
    true
  );
}

bool publishRetained(const char* topic, const char* value) {
  if (!mqttClient.connected()) return false;

  return mqttClient.publish(
    topic,
    value,
    true
  );
}

// ============================================================
// HOME ASSISTANT DISCOVERY HELPERS
// ============================================================

void addDeviceInformation(JsonDocument& document) {
  JsonObject device =
    document["device"].to<JsonObject>();

  JsonArray identifiers =
    device["identifiers"].to<JsonArray>();

  identifiers.add(DEVICE_ID);

  device["name"] = DEVICE_NAME;
  device["manufacturer"] = DEVICE_MANUFACTURER;
  device["model"] = DEVICE_MODEL;
  device["sw_version"] = FIRMWARE_VERSION;
}

bool publishDiscoveryJson(
  const String& topic,
  JsonDocument& document
) {
  char payload[1800];

  const size_t needed = measureJson(document);

  if (needed >= sizeof(payload)) {
    Serial.println("Discovery JSON too large");
    return false;
  }

  serializeJson(
    document,
    payload,
    sizeof(payload)
  );

  return mqttClient.publish(
    topic.c_str(),
    payload,
    true
  );
}

void publishSensorDiscovery(
  const char* component,
  const char* objectId,
  const char* name,
  const char* uniqueId,
  const char* stateTopic,
  const char* deviceClass = nullptr,
  const char* stateClass = nullptr,
  const char* unit = nullptr,
  const char* icon = nullptr,
  const char* entityCategory = nullptr
) {
  JsonDocument doc;

  doc["name"] = name;
  doc["unique_id"] = uniqueId;
  doc["state_topic"] = stateTopic;
  doc["availability_topic"] = TOPIC_AVAILABILITY;
  doc["payload_available"] = "online";
  doc["payload_not_available"] = "offline";

  if (deviceClass) {
    doc["device_class"] = deviceClass;
  }

  if (stateClass) {
    doc["state_class"] = stateClass;
  }

  if (unit) {
    doc["unit_of_measurement"] = unit;
  }

  if (icon) {
    doc["icon"] = icon;
  }

  if (entityCategory) {
    doc["entity_category"] = entityCategory;
  }

  addDeviceInformation(doc);

  String topic = "homeassistant/";
  topic += component;
  topic += "/";
  topic += DEVICE_ID;
  topic += "/";
  topic += objectId;
  topic += "/config";

  publishDiscoveryJson(topic, doc);
}

void publishBinarySensorDiscovery(
  const char* objectId,
  const char* name,
  const char* uniqueId,
  const char* stateTopic,
  const char* deviceClass = nullptr,
  const char* icon = nullptr,
  const char* entityCategory = nullptr
) {
  JsonDocument doc;

  doc["name"] = name;
  doc["unique_id"] = uniqueId;
  doc["state_topic"] = stateTopic;
  doc["availability_topic"] = TOPIC_AVAILABILITY;
  doc["payload_on"] = "ON";
  doc["payload_off"] = "OFF";

  if (deviceClass) {
    doc["device_class"] = deviceClass;
  }

  if (icon) {
    doc["icon"] = icon;
  }

  if (entityCategory) {
    doc["entity_category"] = entityCategory;
  }

  addDeviceInformation(doc);

  String topic = "homeassistant/binary_sensor/";
  topic += DEVICE_ID;
  topic += "/";
  topic += objectId;
  topic += "/config";

  publishDiscoveryJson(topic, doc);
}

void publishButtonDiscovery(
  const char* objectId,
  const char* name,
  const char* uniqueId,
  const char* commandTopic,
  const char* payload,
  const char* icon,
  const char* entityCategory = nullptr
) {
  JsonDocument doc;

  doc["name"] = name;
  doc["unique_id"] = uniqueId;
  doc["command_topic"] = commandTopic;
  doc["payload_press"] = payload;
  doc["availability_topic"] = TOPIC_AVAILABILITY;

  if (icon) {
    doc["icon"] = icon;
  }

  if (entityCategory) {
    doc["entity_category"] = entityCategory;
  }

  addDeviceInformation(doc);

  String topic = "homeassistant/button/";
  topic += DEVICE_ID;
  topic += "/";
  topic += objectId;
  topic += "/config";

  publishDiscoveryJson(topic, doc);
}

// ============================================================
// HOME ASSISTANT DISCOVERY
// ============================================================
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
void loop() {
  maintainWiFi();

  if (
    WiFi.status() ==
      WL_CONNECTED
  ) {
    initialiseTime();
    initialiseOTA();

    if (otaStarted) {
      ArduinoOTA.handle();
    }

    connectMQTT();

    if (
      mqttClient.connected()
    ) {
      mqttClient.loop();

      if (
        millis() -
          lastSensorPublishMs >=
          SENSOR_PUBLISH_INTERVAL_MS
      ) {
        lastSensorPublishMs =
          millis();

        publishMeasurements();
      }

      if (
        millis() -
          lastNetworkPublishMs >=
          NETWORK_PUBLISH_INTERVAL_MS
      ) {
        lastNetworkPublishMs =
          millis();

        publishDiagnostics();
      }
    }
  }

  updateEmitterSchedule();
  monitorIRReceiver();

  // Monday-Saturday 07:30-17:00: remain awake and monitor for every delivery.
  // After each genuine delivery the emitter pauses for 30 seconds, then rearms.
  // Overnight and Sunday: IR is OFF and the ESP sleeps in 60-minute chunks.
  manageScheduledDeepSleep();

  delay(5);
}

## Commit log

2026-07-26 Update device manufacturer name to 'Darksplat'
2026-07-27 Add PCB hardware documentation
2026-07-27 Document custom Letterbox Sentinel PCB
2026-07-27 Add KiCad source notes
2026-07-27 Add current NPTH drill output
    [Letterbox_Sentinel-NPTH.drl]
2026-07-27 Add current plated drill output
    [Letterbox_Sentinel-PTH.drl]
2026-07-27 Add PCB manufacturing notes
2026-07-27 Clarify KiCad source upload status
2026-08-05 Updated all files and directories
    [Letterbox_Sentinel.kicad_pcb, Letterbox_Sentinel.kicad_sch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]
2026-10-02 Add XIAO ESP32-C6 carrier PCB review revision without BME280
    [Letterbox_Sentinel_C6.kicad_pcb, Letterbox_Sentinel_C6.kicad_sch]

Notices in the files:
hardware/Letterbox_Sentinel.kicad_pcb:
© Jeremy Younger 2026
